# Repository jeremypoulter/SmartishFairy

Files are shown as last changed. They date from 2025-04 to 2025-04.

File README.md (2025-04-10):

# SmartishFairy

## Overview
SmartishFairy is a smart controller for inexpensive consumer fairy lights that provides advanced control features at an affordable price. This project allows you to transform ordinary fairy light strings into programmable, dynamic lighting installations with various effects and control options.

### Key Features
- Control up to 12 output channels (6 pairs of lights)
- Support for high voltage input (up to 50V)
- Multiple operating modes for different control schemes
- Compatible with common lighting protocols (WS2812, SPI)
- Based on the powerful RP2040 microcontroller
- Cost-effective solution for home or commercial lighting displays

## Hardware Specifications

### Power and Output
- Input voltage: up to 50V DC
- Output channels: 12 channels total (6 sets, assuming 2 channels per set)
- Driver: 3 × L6226QTR dual channel motor drivers

### Driver Configuration
- Each driver has separate input - jumper available to link input rails
- Output side presents source voltage and ground for independent channels

### Pin Requirements
- 12 output pins (for driving the L6226QTR controllers)
- 8 configuration pins
- 3 SPI pins (possibly 4 if chip select is needed)
- Based on the RP2040 microcontroller

## Operating Modes

### Output Modes (2 bits per driver, 6 bits total)
| Mode | Description |
|---|---|
| 0 | Switching - Simple on/off control |
| 1 | TBD (Reserved for future implementation) |
| 2 | Independent high is on - Active high control |
| 3 | Independent low is on - Active low control |

### Input Modes (2 bits)
| Mode | Protocol | Description |
|---|---|---|
| 0 | WS2812 | Neopixel-compatible protocol |
| 1 | SPI | Standard SPI interface |
| 2 | RGB | RGB values converted to brightness (12 virtual RGB lights map to 12 outputs) |
| 3 | Single | Each input channel controls an output (4 virtual RGB elements map to 12 output channels) |

## Installation and Setup

### Hardware Requirements
- RP2040-based board (such as Raspberry Pi Pico)
- 3 × L6226QTR dual channel motor drivers
- Appropriate power supply (rated for your fairy lights, up to 50V)
- Connecting wires/jumpers
- Fairy light strings (compatible with the voltage of your setup)

### Wiring
1. Connect the RP2040 to the L6226QTR drivers according to the pin mapping in the firmware
2. Set configuration jumpers according to your desired operating mode
3. Connect the power supply to the input rails
4. Connect fairy lights to the output channels

For detailed wiring diagrams, refer to the `docs/wiring.md` file in this repository.

## Firmware Setup

### Prerequisites
- C/C++ development environment for RP2040
- Raspberry Pi Pico SDK
- USB cable for programming

### Installation Steps
1. Clone this repository
   ```
   git clone https://github.com/JeremyPoulter/SmartishFairy.git
   ```
2. Configure the firmware based on your setup
3. Compile and flash to the RP2040 board

For detailed firmware instructions, see `docs/firmware.md`.

## Usage Examples

### Basic Control
To control the lights with basic on/off functionality, set the output mode to 0 (switching).

### RGB Control
To use RGB color control:
1. Set the input mode to 2 (RGB)
2. Send RGB color values via the configured input protocol
3. The controller automatically maps these values to brightness levels on the physical outputs

### Independent Channel Control
For direct control of individual channels:
1. Set the input mode to 3 (Single)
2. Control each output channel independently

## Troubleshooting

| Problem | Possible Solution |
|---|---|
| No lights turn on | Check power supply and connections |
| Lights flicker unexpectedly | Verify ground connections and check for EMI sources |
| Cannot program the controller | Ensure USB connection is secure and drivers are installed |

## Resources
- [RP2040 Hardware Design Guide](https://datasheets.raspberrypi.com/rp2040/hardware-design-with-rp2040.pdf)
- [L6226QTR Datasheet](https://www.st.com/resource/en/datasheet/l6226q.pdf)

## Contributing
Contributions to the SmartishFairy project are welcome! Please feel free to submit pull requests or open issues for bugs, questions, or feature requests.

## License
This project is licensed under the MIT License - see the LICENSE file for details.

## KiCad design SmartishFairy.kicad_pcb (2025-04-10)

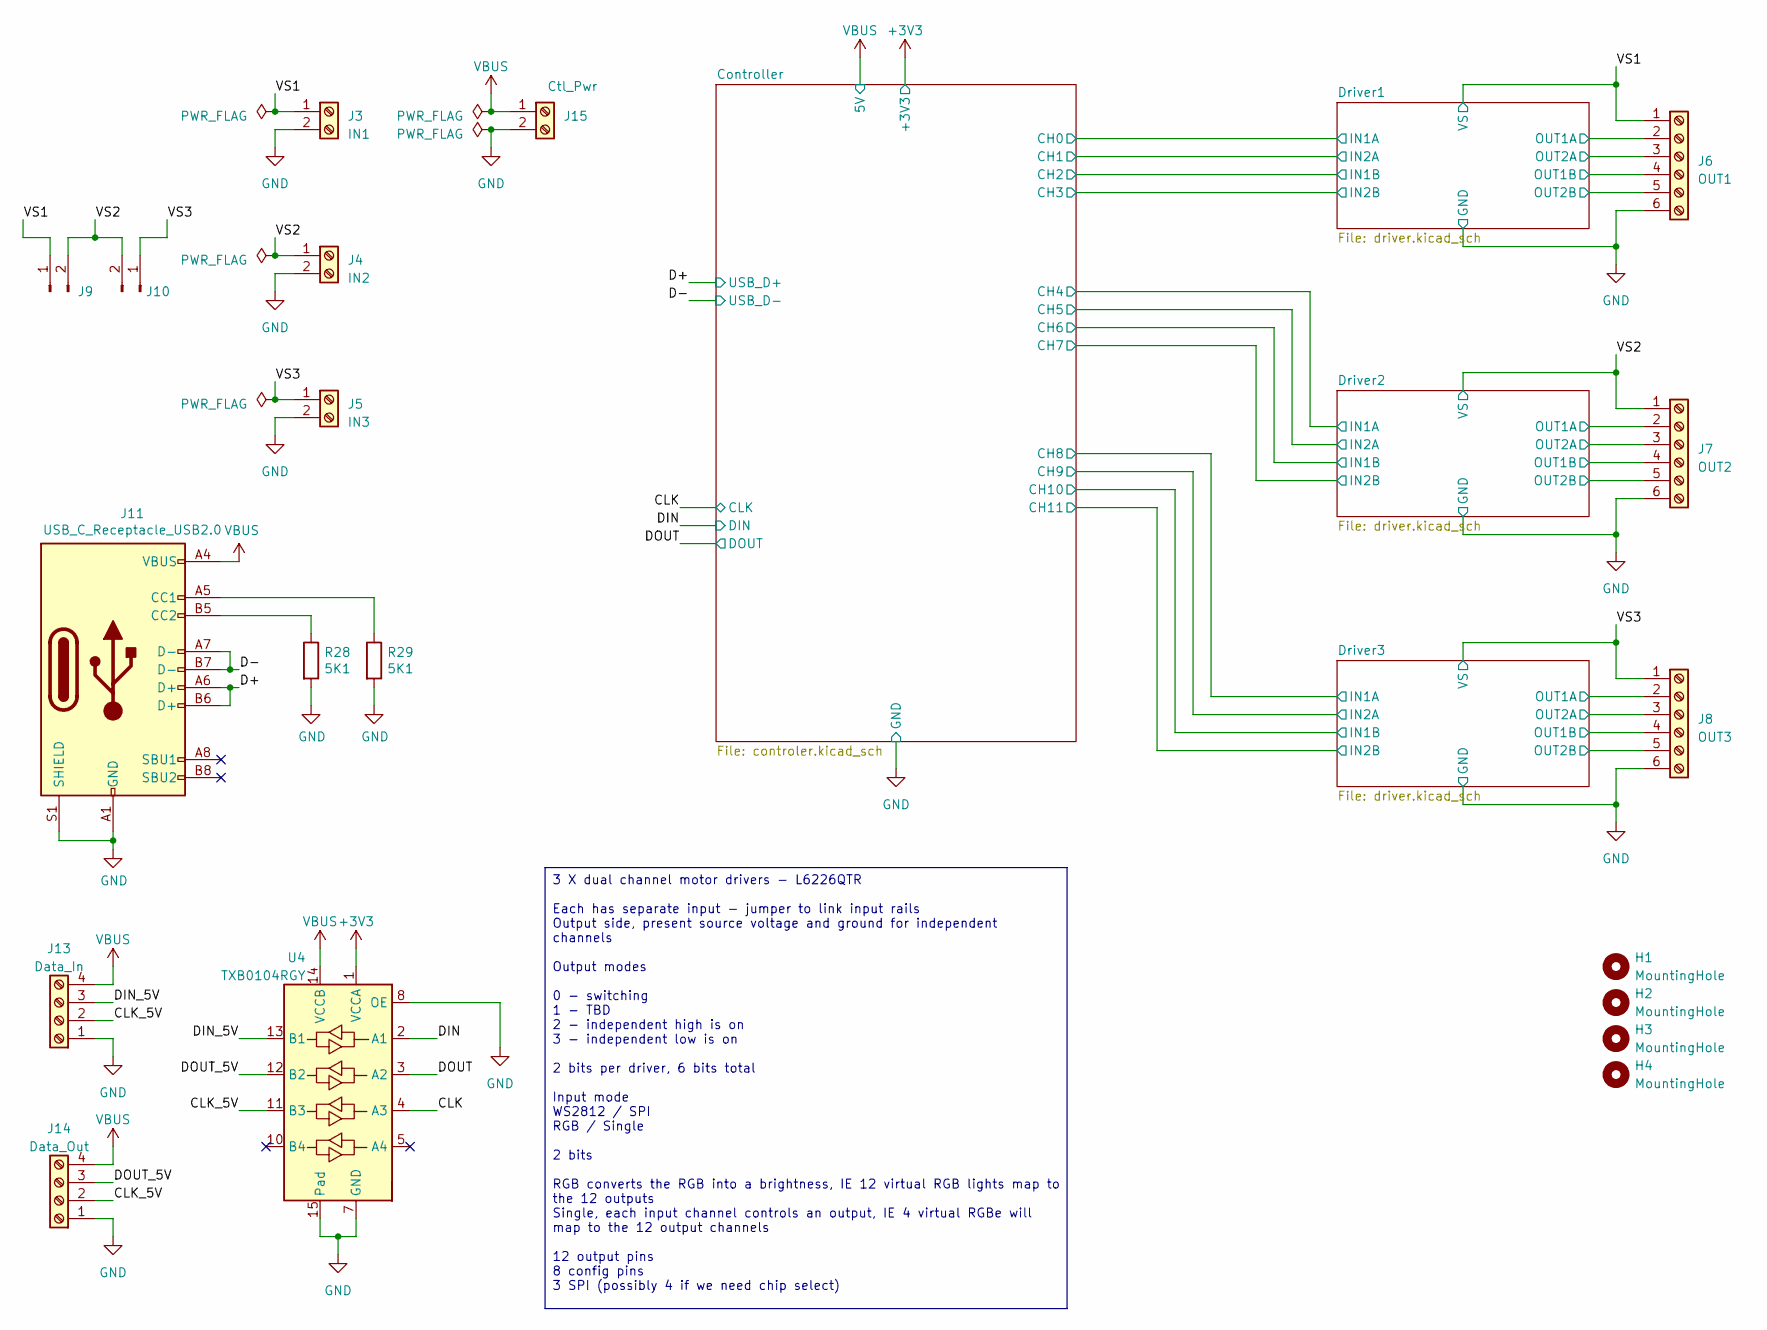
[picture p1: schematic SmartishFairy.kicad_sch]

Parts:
H1, H2, H3, H4: MountingHole; MountingHole_3mm
J3: IN1; TerminalBlock_TE_282834-2_1x02_P2.54mm_Horizontal
J4: IN2; TerminalBlock_TE_282834-2_1x02_P2.54mm_Horizontal
J5: IN3; TerminalBlock_TE_282834-2_1x02_P2.54mm_Horizontal
J6: OUT1; TerminalBlock_TE_282834-6_1x06_P2.54mm_Horizontal
J7: OUT2; TerminalBlock_TE_282834-6_1x06_P2.54mm_Horizontal
J8: OUT3; TerminalBlock_TE_282834-6_1x06_P2.54mm_Horizontal
J9, J10: Conn_01x02_Pin; PinHeader_1x02_P2.54mm_Vertical
J11: USB_C_Receptacle_USB2.0; USB_C_Receptacle_HRO_TYPE-C-31-M-12; LCSC C165948
J13: Data_In; TerminalBlock_TE_282834-4_1x04_P2.54mm_Horizontal
J14: Data_Out; TerminalBlock_TE_282834-4_1x04_P2.54mm_Horizontal
J15: Ctl_Pwr; TerminalBlock_TE_282834-2_1x02_P2.54mm_Horizontal
R28, R29: 5K1; R_0402_1005Metric
U4: TXB0104RGY; Texas_S-PVQFN-N14

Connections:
+3V3: U4.1 (VCCA); also elsewhere on the board
/CLK: U4.4 (A3); also elsewhere on the board
/CLK_5V: J13.2, J14.2, U4.11 (B3)
/D+: J11.A6 (D+), J11.B6 (D+); also elsewhere on the board
/D-: J11.A7 (D-), J11.B7 (D-); also elsewhere on the board
/DIN: U4.2 (A1); also elsewhere on the board
/DIN_5V: J13.3, U4.13 (B1)
/DOUT: U4.3 (A2); also elsewhere on the board
/DOUT_5V: J14.3, U4.12 (B2)
/Driver1/OUT1A: J6.2; also elsewhere on the board
/Driver1/OUT1B: J6.4; also elsewhere on the board
/Driver1/OUT2A: J6.3; also elsewhere on the board
/Driver1/OUT2B: J6.5; also elsewhere on the board
/Driver2/OUT1A: J7.2; also elsewhere on the board
/Driver2/OUT1B: J7.4; also elsewhere on the board
/Driver2/OUT2A: J7.3; also elsewhere on the board
/Driver2/OUT2B: J7.5; also elsewhere on the board
/Driver3/OUT1A: J8.2; also elsewhere on the board
/Driver3/OUT1B: J8.4; also elsewhere on the board
/Driver3/OUT2A: J8.3; also elsewhere on the board
/Driver3/OUT2B: J8.5; also elsewhere on the board
/VS1: J3.1, J6.1, J9.1; also elsewhere on the board
/VS2: J4.1, J7.1, J9.2, J10.2; also elsewhere on the board
/VS3: J5.1, J8.1, J10.1; also elsewhere on the board
GND: J3.2, J4.2, J5.2, J6.6, J7.6, J8.6, J11.A1 (GND), J11.A12 (GND), J11.B1 (GND), J11.B12 (GND), J11.S1 (SHIELD), J13.1, J14.1, J15.2, R28.2, R29.2, U4.7 (GND), U4.8 (OE), U4.15 (Pad); also elsewhere on the board
unnamed: J11.A5 (CC1), R29.1
unnamed: J11.B5 (CC2), R28.1
VBUS: J11.A4 (VBUS), J11.A9 (VBUS), J11.B4 (VBUS), J11.B9 (VBUS), J13.4, J14.4, J15.1, U4.14 (VCCB); also elsewhere on the board

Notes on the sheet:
3 X dual channel motor drivers - L6226QTR Each has separate input - jumper to link input rails Output side, present source voltage and ground for independent channels Output modes 0 - switching 1 - TBD 2 - independent high is on 3 - independent low is on 2 bits per driver, 6 bits total Input mode W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

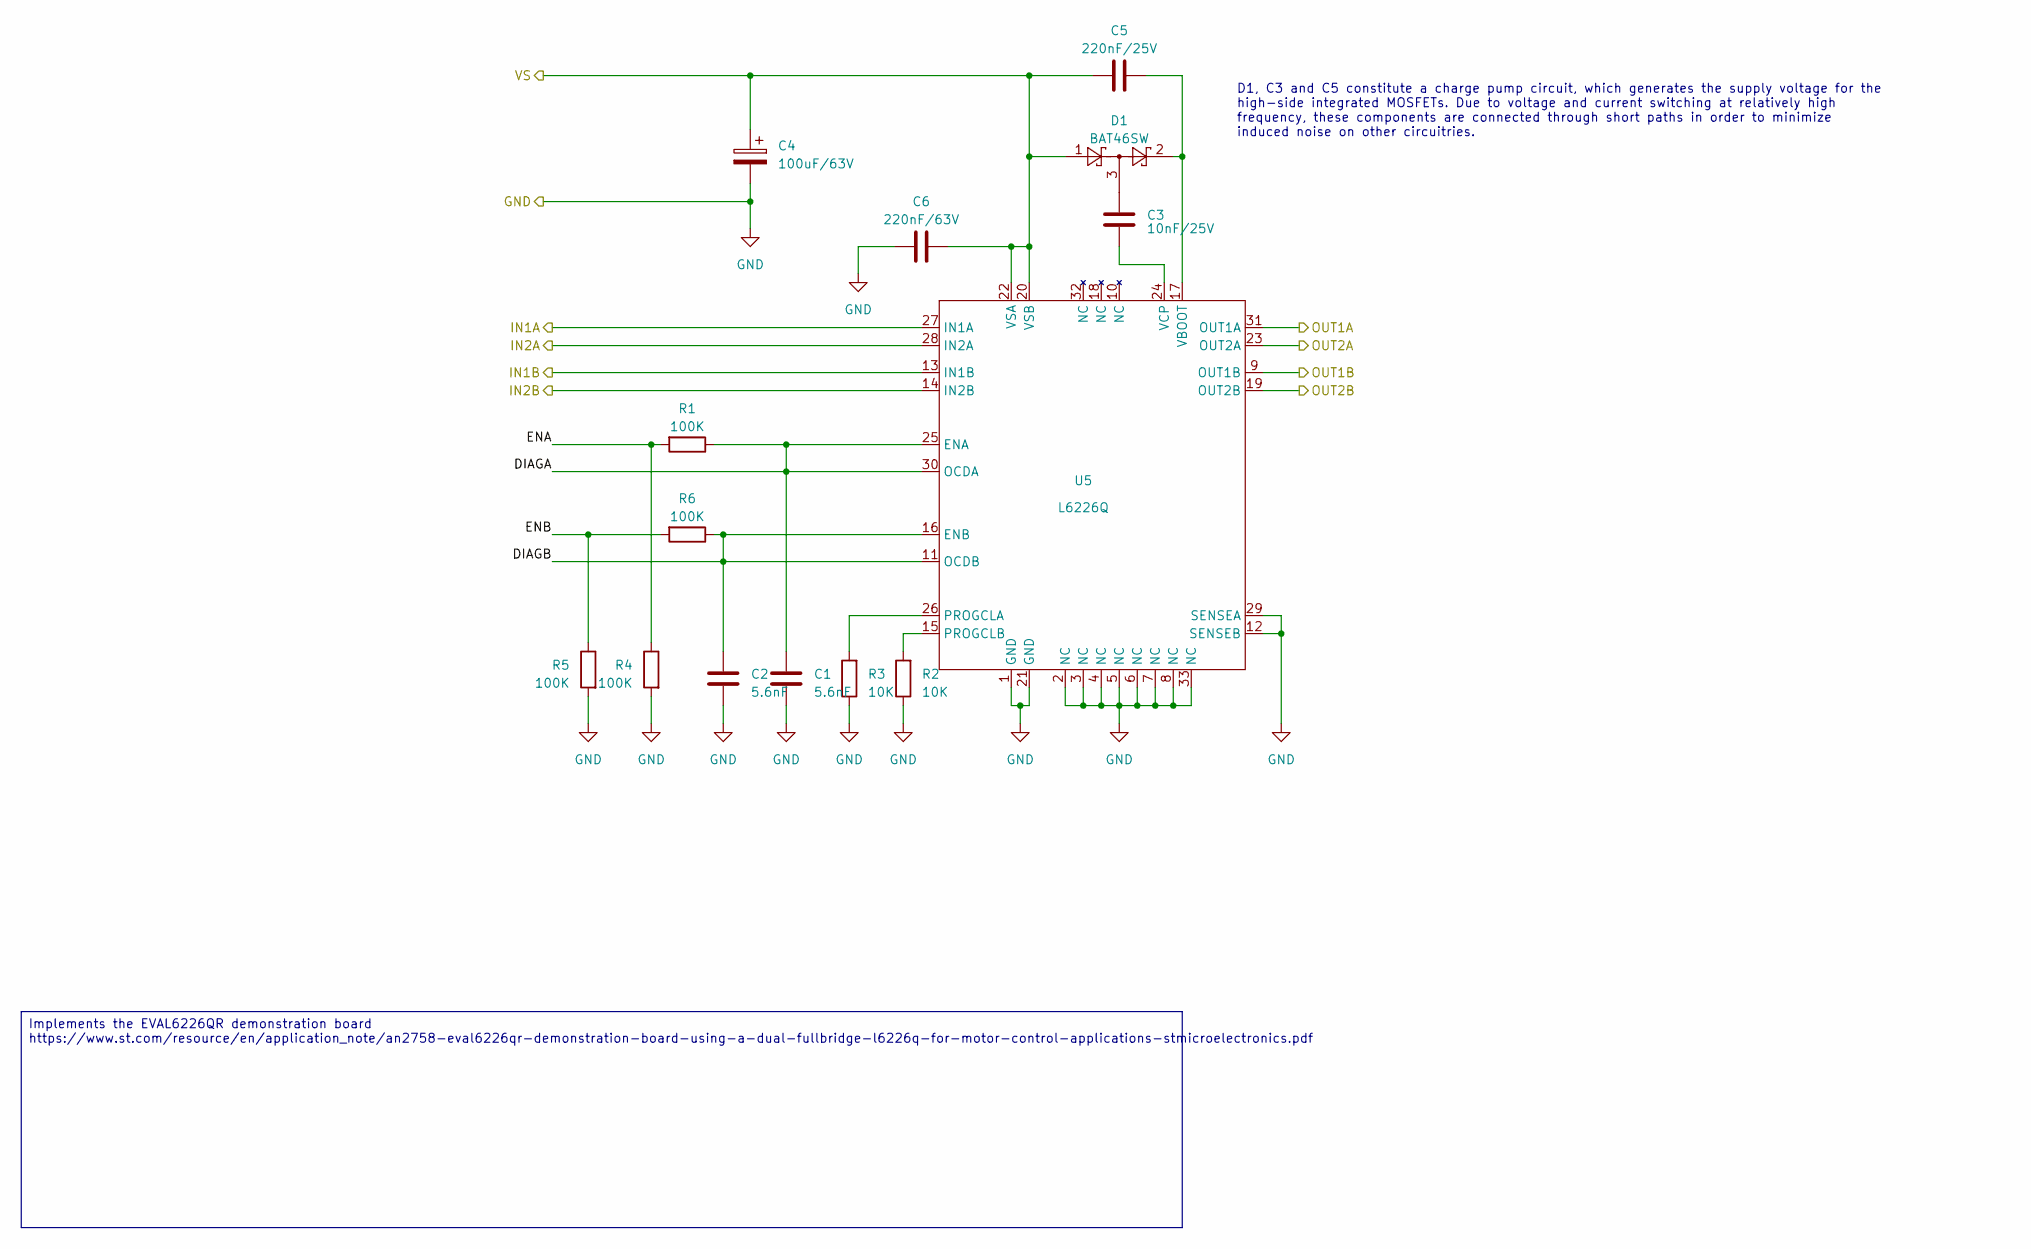
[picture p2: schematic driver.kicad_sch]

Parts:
C1, C2: 5.6nF; C_0603_1608Metric
C3: 10nF/25V; C_0603_1608Metric
C4: 100uF/63V; CP_Elec_5x4.4
C5: 220nF/25V; C_0603_1608Metric
C6: 220nF/63V; C_0603_1608Metric
D1: BAT46SW; SOT-23
R1, R4, R5, R6: 100K; R_0603_1608Metric
R2, R3: 10K; R_0603_1608Metric
U5: L6226Q; QFN-32-1EP_5x5mm_P0.5mm_EP3.1x3.1mm

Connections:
/Controller/CH0: U5.27 (IN1A); also elsewhere on the board
/Controller/CH1: U5.28 (IN2A); also elsewhere on the board
/Controller/CH2: U5.13 (IN1B); also elsewhere on the board
/Controller/CH3: U5.14 (IN2B); also elsewhere on the board
/Driver1/DIAGA: C1.1, R1.1, U5.25 (ENA), U5.30 (OCDA)
/Driver1/DIAGB: C2.1, R6.1, U5.11 (OCDB), U5.16 (ENB)
/Driver1/ENA: R1.2, R4.1
/Driver1/ENB: R5.1, R6.2
/Driver1/OUT1A: U5.31 (OUT1A); also elsewhere on the board
/Driver1/OUT1B: U5.9 (OUT1B); also elsewhere on the board
/Driver1/OUT2A: U5.23 (OUT2A); also elsewhere on the board
/Driver1/OUT2B: U5.19 (OUT2B); also elsewhere on the board
/VS1: C4.1, C5.1, C6.2, D1.1, U5.20 (VSB), U5.22 (VSA); also elsewhere on the board
GND: C1.2, C2.2, C4.2, C6.1, R2.1, R3.1, R4.2, R5.2, U5.1 (GND), U5.2 (NC), U5.3 (NC), U5.4 (NC), U5.5 (NC), U5.6 (NC), U5.7 (NC), U5.8 (NC), U5.12 (SENSEB), U5.21 (GND), U5.29 (SENSEA), U5.33 (NC); also elsewhere on the board
unnamed: C3.1, D1.3
unnamed: R3.2, U5.26 (PROGCLA)
unnamed: R2.2, U5.15 (PROGCLB)
unnamed: C5.2, D1.2, U5.17 (VBOOT)
unnamed: C3.2, U5.24 (VCP)

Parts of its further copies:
C7, C9, C13, C15: 5.6nF; C_0603_1608Metric
C8, C14: 100uF/63V; CP_Elec_5x4.4
C10, C16: 220nF/63V; C_0603_1608Metric
C11, C17: 220nF/25V; C_0603_1608Metric
C12, C18: 10nF/25V; C_0603_1608Metric
D2, D3: BAT46SW; SOT-23
R7, R8, R9, R10, R13, R14, R15, R16: 100K; R_0603_1608Metric
R11, R12, R17, R18: 10K; R_0603_1608Metric
U6, U7: L6226Q; QFN-32-1EP_5x5mm_P0.5mm_EP3.1x3.1mm

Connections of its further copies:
/Controller/CH4: U6.27 (IN1A); also elsewhere on the board
/Controller/CH5: U6.28 (IN2A); also elsewhere on the board
/Controller/CH6: U6.13 (IN1B); also elsewhere on the board
/Controller/CH7: U6.14 (IN2B); also elsewhere on the board
/Controller/CH8: U7.27 (IN1A); also elsewhere on the board
/Controller/CH9: U7.28 (IN2A); also elsewhere on the board
/Controller/CH10: U7.13 (IN1B); also elsewhere on the board
/Controller/CH11: U7.14 (IN2B); also elsewhere on the board
/Driver2/DIAGA: C9.1, R9.1, U6.25 (ENA), U6.30 (OCDA)
/Driver2/DIAGB: C7.1, R10.1, U6.11 (OCDB), U6.16 (ENB)
/Driver2/ENA: R8.1, R9.2
/Driver2/ENB: R7.1, R10.2
/Driver2/OUT1A: U6.31 (OUT1A); also elsewhere on the board
/Driver2/OUT1B: U6.9 (OUT1B); also elsewhere on the board
/Driver2/OUT2A: U6.23 (OUT2A); also elsewhere on the board
/Driver2/OUT2B: U6.19 (OUT2B); also elsewhere on the board
/Driver3/DIAGA: C15.1, R15.1, U7.25 (ENA), U7.30 (OCDA)
/Driver3/DIAGB: C13.1, R16.1, U7.11 (OCDB), U7.16 (ENB)
/Driver3/ENA: R14.1, R15.2
/Driver3/ENB: R13.1, R16.2
/Driver3/OUT1A: U7.31 (OUT1A); also elsewhere on the board
/Driver3/OUT1B: U7.9 (OUT1B); also elsewhere on the board
/Driver3/OUT2A: U7.23 (OUT2A); also elsewhere on the board
/Driver3/OUT2B: U7.19 (OUT2B); also elsewhere on the board
/VS2: C8.1, C10.2, C11.1, D2.1, U6.20 (VSB), U6.22 (VSA); also elsewhere on the board
/VS3: C14.1, C16.2, C17.1, D3.1, U7.20 (VSB), U7.22 (VSA); also elsewhere on the board
GND: C7.2, C8.2, C9.2, C10.1, C13.2, C14.2, C15.2, C16.1, R7.2, R8.2, R11.1, R12.1, R13.2, R14.2, R17.1, R18.1, U6.1 (GND), U6.2 (NC), U6.3 (NC), U6.4 (NC), U6.5 (NC), U6.6 (NC), U6.7 (NC), U6.8 (NC), U6.12 (SENSEB), U6.21 (GND), U6.29 (SENSEA), U6.33 (NC), U7.1 (GND), U7.2 (NC), U7.3 (NC), U7.4 (NC), U7.5 (NC), U7.6 (NC), U7.7 (NC), U7.8 (NC), U7.12 (SENSEB), U7.21 (GND), U7.29 (SENSEA), U7.33 (NC); also elsewhere on the board
unnamed: C12.1, D2.3
unnamed: C18.1, D3.3
unnamed: R11.2, U6.26 (PROGCLA)
unnamed: R12.2, U6.15 (PROGCLB)
unnamed: C11.2, D2.2, U6.17 (VBOOT)
unnamed: C12.2, U6.24 (VCP)
unnamed: R17.2, U7.26 (PROGCLA)
unnamed: R18.2, U7.15 (PROGCLB)
unnamed: C17.2, D3.2, U7.17 (VBOOT)
unnamed: C18.2, U7.24 (VCP)

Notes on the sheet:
D1, C3 and C5 constitute a charge pump circuit, which generates the supply voltage for the high-side integrated MOSFETs. Due to voltage and current switching at relatively high frequency, these components are connected through short paths in order to minimize induced noise on other circuitries.
Implements the EVAL6226QR demonstration board https://www.st.com/resource/en/application_note/an2758-eval6226qr-demonstration-board-using-a-dual-fullbridge-l6226q-for-motor-control-applications-stmicroelectronic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

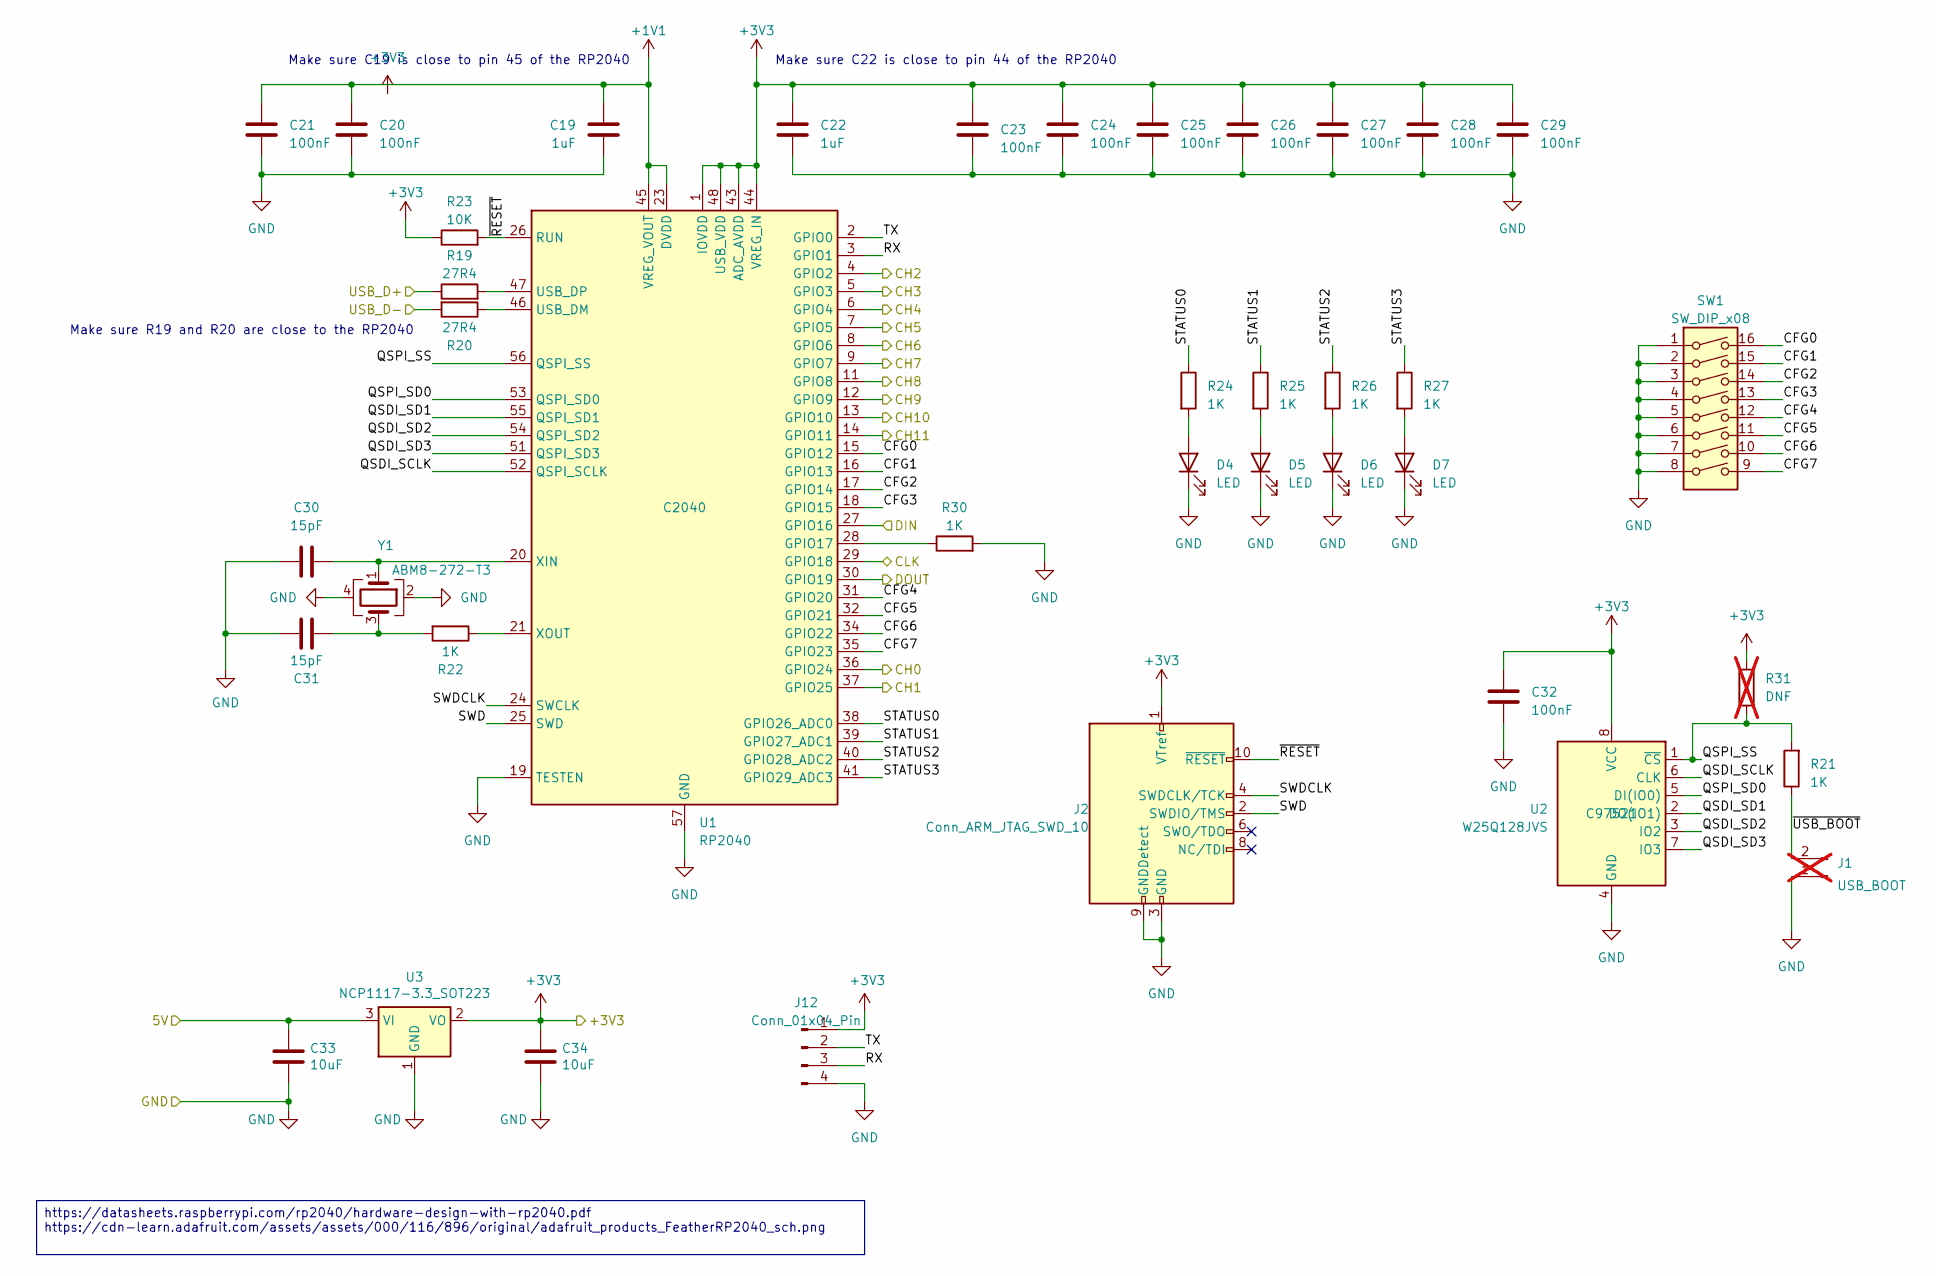
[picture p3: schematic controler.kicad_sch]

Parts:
C19, C22: 1uF; C_0402_1005Metric
C20, C21, C23, C24, C25, C26, C27, C28, C29, C32: 100nF; C_0402_1005Metric
C30, C31: 15pF; C_0402_1005Metric
C33, C34: 10uF; C_0603_1608Metric
D4, D5, D6, D7: LED; LED_0805_2012Metric
J1: USB_BOOT; PinHeader_1x02_P2.54mm_Vertical; not fitted
J2: Conn_ARM_JTAG_SWD_10; PinHeader_2x05_P1.27mm_Vertical_SMD
J12: Conn_01x04_Pin; PinHeader_1x04_P2.54mm_Vertical
R19, R20: 27R4; R_0402_1005Metric
R21, R22, R24, R25, R26, R27, R30: 1K; R_0402_1005Metric
R23: 10K; R_0402_1005Metric
R31: DNF; R_0402_1005Metric; not fitted
SW1: SW_DIP_x08; SW_DIP_SPSTx08_Slide_9.78x22.5mm_W7.62mm_P2.54mm
U1: RP2040; QFN-56-1EP_7x7mm_P0.4mm_EP3.2x3.2mm; LCSC C2040
U2: W25Q128JVS; SOIC-8_5.23x5.23mm_P1.27mm; LCSC C97521
U3: NCP1117-3.3_SOT223; SOT-223-3_TabPin2
Y1: ABM8-272-T3; Crystal_SMD_3225-4Pin_3.2x2.5mm; LCSC C20625731

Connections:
+1V1: C19.1, C20.1, C21.1, U1.23 (DVDD), U1.45 (VREG_VOUT), U1.50 (DVDD)
+3V3: C22.1, C23.1, C24.1, C25.1, C26.1, C27.1, C28.1, C29.1, C32.1, C34.1, J2.1 (VTref), J12.1, R23.1, R31.2, U1.1 (IOVDD), U1.10 (IOVDD), U1.22 (IOVDD), U1.33 (IOVDD), U1.42 (IOVDD), U1.43 (ADC_AVDD), U1.44 (VREG_IN), U1.48 (USB_VDD), U1.49 (IOVDD), U2.8 (VCC), U3.2 (VO); also elsewhere on the board
/CLK: U1.29 (GPIO18); also elsewhere on the board
/Controller/CFG0: SW1.16, U1.15 (GPIO12)
/Controller/CFG1: SW1.15, U1.16 (GPIO13)
/Controller/CFG2: SW1.14, U1.17 (GPIO14)
/Controller/CFG3: SW1.13, U1.18 (GPIO15)
/Controller/CFG4: SW1.12, U1.31 (GPIO20)
/Controller/CFG5: SW1.11, U1.32 (GPIO21)
/Controller/CFG6: SW1.10, U1.34 (GPIO22)
/Controller/CFG7: SW1.9, U1.35 (GPIO23)
/Controller/CH0: U1.36 (GPIO24); also elsewhere on the board
/Controller/CH1: U1.37 (GPIO25); also elsewhere on the board
/Controller/CH2: U1.4 (GPIO2); also elsewhere on the board
/Controller/CH3: U1.5 (GPIO3); also elsewhere on the board
/Controller/CH4: U1.6 (GPIO4); also elsewhere on the board
/Controller/CH5: U1.7 (GPIO5); also elsewhere on the board
/Controller/CH6: U1.8 (GPIO6); also elsewhere on the board
/Controller/CH7: U1.9 (GPIO7); also elsewhere on the board
/Controller/CH8: U1.11 (GPIO8); also elsewhere on the board
/Controller/CH9: U1.12 (GPIO9); also elsewhere on the board
/Controller/CH10: U1.13 (GPIO10); also elsewhere on the board
/Controller/CH11: U1.14 (GPIO11); also elsewhere on the board
/Controller/QSDI_SCLK: U1.52 (QSPI_SCLK), U2.6 (CLK)
/Controller/QSDI_SD1: U1.55 (QSPI_SD1), U2.2 (DO(IO1))
/Controller/QSDI_SD2: U1.54 (QSPI_SD2), U2.3 (IO2)
/Controller/QSDI_SD3: U1.51 (QSPI_SD3), U2.7 (IO3)
/Controller/QSPI_SD0: U1.53 (QSPI_SD0), U2.5 (DI(IO0))
/Controller/QSPI_SS: R21.2, R31.1, U1.56 (QSPI_SS), U2.1 (~CS)
/Controller/RX: J12.3, U1.3 (GPIO1)
/Controller/STATUS0: R24.1, U1.38 (GPIO26_ADC0)
/Controller/STATUS1: R25.1, U1.39 (GPIO27_ADC1)
/Controller/STATUS2: R26.1, U1.40 (GPIO28_ADC2)
/Controller/STATUS3: R27.1, U1.41 (GPIO29_ADC3)
/Controller/SWD: J2.2 (SWDIO/TMS), U1.25 (SWD)
/Controller/SWDCLK: J2.4 (SWDCLK/TCK), U1.24 (SWCLK)
/Controller/TX: J12.2, U1.2 (GPIO0)
/Controller/~RESET: J2.10 (~RESET), R23.2, U1.26 (RUN)
/Controller/~USB_BOOT: J1.2, R21.1
/D+: R19.1; also elsewhere on the board
/D-: R20.2; also elsewhere on the board
/DIN: U1.27 (GPIO16); also elsewhere on the board
/DOUT: U1.30 (GPIO19); also elsewhere on the board
GND: C19.2, C20.2, C21.2, C22.2, C23.2, C24.2, C25.2, C26.2, C27.2, C28.2, C29.2, C30.1, C31.2, C32.2, C33.2, C34.2, D4.1 (K), D5.1 (K), D6.1 (K), D7.1 (K), J1.1, J2.3 (GND), J2.5 (GND), J2.9 (GNDDetect), J12.4, R30.2, SW1.1, SW1.2, SW1.3, SW1.4, SW1.5, SW1.6, SW1.7, SW1.8, U1.19 (TESTEN), U1.57 (GND), U2.4 (GND), U3.1 (GND), Y1.2, Y1.4; also elsewhere on the board
unnamed: C31.1, R22.2, Y1.3
unnamed: D4.2 (A), R24.2
unnamed: D5.2 (A), R25.2
unnamed: D6.2 (A), R26.2
unnamed: D7.2 (A), R27.2
unnamed: R30.1, U1.28 (GPIO17)
unnamed: R20.1, U1.46 (USB_DM)
unnamed: R19.2, U1.47 (USB_DP)
unnamed: C30.2, U1.20 (XIN), Y1.1
unnamed: R22.1, U1.21 (XOUT)
VBUS: C33.1, U3.3 (VI); also elsewhere on the board

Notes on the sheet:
Make sure C22 is close to pin 44 of the RP2040
Make sure C19 is close to pin 45 of the RP2040
Make sure R19 and R20 are close to the RP2040
https://datasheets.raspberrypi.com/rp2040/hardware-design-with-rp2040.pdf https://cdn-learn.adafruit.com/assets/assets/000/116/896/original/adafruit_products_FeatherRP2040_sch.png

Board: 2 copper layers, 100 parts (0 on the bottom side), 102 nets, no tracks yet.

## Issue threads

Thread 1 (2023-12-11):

Battery version

jeremypoulter, 2023-12-11:
We could be a battery version:

- Single cell LiPo battery
- Recharging circuits
- Buck/Boost DC-to-DC converter for 3v/4.5v/5v output
- Less channels
- ESP32

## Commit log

2023-03-19 ECR fixes
    [SmartishFairy.kicad_sch, controler.kicad_sch, driver.kicad_sch]
2023-03-19 Ignore temp/generated KiCAD
2023-03-19 Remove old file
    [power.kicad_sch]
2023-03-19 More ECR fixes
    [SmartishFairy.kicad_sch, controler.kicad_sch]
2023-03-19 Initial PCB layout
    [SmartishFairy.kicad_pcb]
2025-01-10 Layout WIP
    [SmartishFairy.kicad_pcb, SmartishFairy.kicad_sch, controler.kicad_sch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]
2025-03-20 Convert to KiCAD v9 and basic sort out of components
    [SmartishFairy.kicad_pcb, SmartishFairy.kicad_sch, controler.kicad_sch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]
2025-04-09 Additional layout
    [SmartishFairy.kicad_pcb, SmartishFairy.kicad_sch, controler.kicad_sch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]
2025-04-09 Added notes about features/control
    [SmartishFairy.kicad_sch]
2025-04-10 Added optional pull up resistor for flash chip
    [SmartishFairy.kicad_pcb, controler.kicad_sch]
2025-04-10 Added a few JLC part number
    [SmartishFairy.kicad_sch, controler.kicad_sch]
2025-04-10 More updates
    Placed more components
    Updated 3D models
    [SmartishFairy.kicad_pcb, SmartishFairy.kicad_sch, controler.kicad_sch]
